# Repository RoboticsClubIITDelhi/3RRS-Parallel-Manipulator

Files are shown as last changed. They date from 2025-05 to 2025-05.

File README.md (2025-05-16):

# Robotics Project 2025

<div align="center">
  
  
  
  <div align="center">
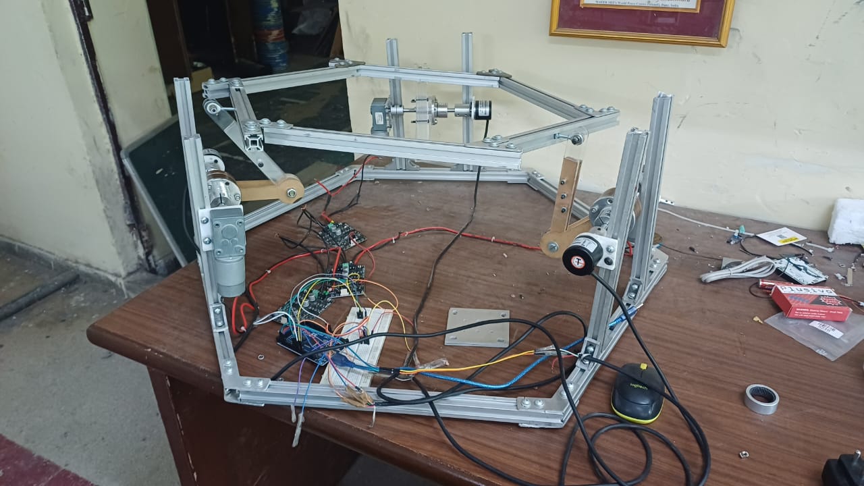
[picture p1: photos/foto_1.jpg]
Project Image
    
    <br> 
  </div>
</div>

## 🤖 Project Overview

This repository houses the codebase for the **3RRS Parallel Manipulator**. It serves as a comprehensive collection of resources, including code, CAD models, calculations, and component datasheets. We aim to create a well-documented reference that will enable future teams to build upon our work.

### 🎯 Key Features

- ✅ Robust Mechanism Design
- ✅ Efficient and Fast Inverse Kinematics
- ✅ Precise Orientation with minimal lag

## 🧠 Algorithm Development
The Inverse Kinematics have been completely solved, coded, and used in multiple applications, one being a ball balancing robot. 

## 📚 Resources
- [Intro to Serial and Parallel Manipulators](https://youtu.be/ZZrNe40jpSA?si=esQ4bNgmhpNv93w0)
- [Inverse Kinematics with the example of a Ball Balancing Bot](https://youtu.be/-1pX518wlu8?si=GbBtG65QNJ148i5c)
- [Research Paper on Kinematics and Dynamics of a 3RRS Parallel Manipulator](https://www.researchgate.net/publication/3902626_Inverse_kinematics_and_dynamics_of_the_3-RRS_parallel_platform)

### Software Utilised
- Autodesk Fusion 360
- Python
- Arduino IDE

### Hardware Utilised
- DC Geared Motors
- Rotary Encoders
- Motor Drivers
- Arduino Mega

## 🤝 Contributor Notes
- We follow the [standard Git workflow](https://www.geeksforgeeks.org/git-workflows-with-open-source-collaboration/) for collaboration
- Suggestions for improvement are welcome via **Issues** or Discussions.

---

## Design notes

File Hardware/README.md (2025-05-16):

# Hardware Documentation

<div align="center">
  
  
  
</div>

## 🔧 Hardware Specifications

- **Dimensions**: 700x800x180mm 
- **Sensors**: Rotary Encoders
- **Power**: 11.1V LiPo battery

## 🔌 Electronics Design

### Base Configuration
- **Microcontroller**: Arduino Mega 2560
- **Motor Driver**: Cytron MDD10A
- **Sensor Interface**: Interrupt based rotary encoders

## 📋 Bill of Materials
1. [DC Motors](https://robu.in/product/et-wgm58-a-high-torque-low-noise-90-degree-right-angle-1-100rpm-12v-dc-worm-gear-motor/) x 3
2. [Rotary Encoders](https://robu.in/product/incremental-optical-rotary-encoder-6002400-pulse-600-ppr/) x 3
3. [Motor Drivers](https://robu.in/product/dual-channel-enhanced-13amp-dc-motor-driver-30a-peak/) x 2
4. [Arduino Mega](https://robu.in/product/original-arduino-mega-2560-atmega2560-mcu-rev3/) x 1
5. Mechanical Hardware (X-channels, Acrylic, Wheel Hubs, Rod ends) 
---

<div align="center">
  <i>For software documentation, please see the <a href="../CodeBase/README.md">Software README</a></i>
</div>

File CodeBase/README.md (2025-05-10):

# Software Documentation

<div align="center">
  
  
  
</div>

## 📁 Software Architecture

The software for the 3RRS Parallel Manipulator project is designed with precision in mind.
It consists of two major divisions:-
1. Control System for controlling the angle of rotation of motors with the help of a PID controller
2. Inverse Kinematics to calculate the angle of rotation of the three motors for the required orientation and height of the end effector

<div align="center">
  <i>For hardware documentation, please see the <a href="../Hardware/README.md">Hardware README</a></i>
</div>

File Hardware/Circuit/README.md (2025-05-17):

This folder contains the circuit diagram.<br><br>
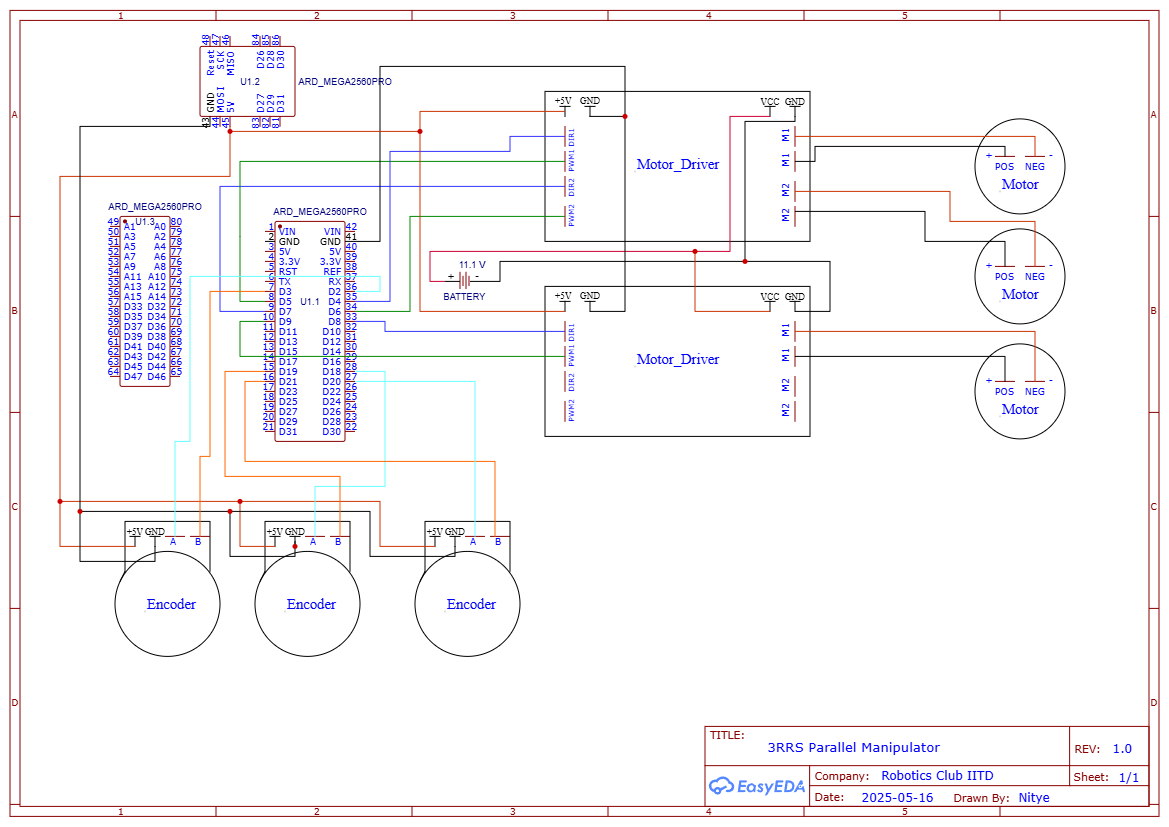
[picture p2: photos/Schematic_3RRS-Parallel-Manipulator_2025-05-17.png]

<h2>Important points</h2>
<ul>
  <li>
   Encoders work based on interrupts, so use a microcontroller with enough interrupt pins; not all pins can handle interrupts.
   In Arduino Uno, there are only 2 interrupt pins which is why we used Arduino Mega, which has 6 pins.
  </li>
  <li>
    Might have to switch the motor driver to a bigger capacity model if using both channels of the driver and using heavy motors.
  </li>
</ul>

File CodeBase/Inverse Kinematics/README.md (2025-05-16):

This folder contains the code for inverse kinematics of the 3RRS Parallel Manipulator.<br>
The Inverse Kinematics is calculated with the help of this research paper.<br>
[Inverse Kinematics and Dynamics of 3RRS Parallel Manipulator](https://www.researchgate.net/publication/3902626_Inverse_kinematics_and_dynamics_of_the_3-RRS_parallel_platform)<br>
This is a simpler video explaining the inverse kinematics.<br>
[Inverse Kinematics of 3RRS Parallel Manipulator](https://www.youtube.com/watch?v=-1pX518wlu8)

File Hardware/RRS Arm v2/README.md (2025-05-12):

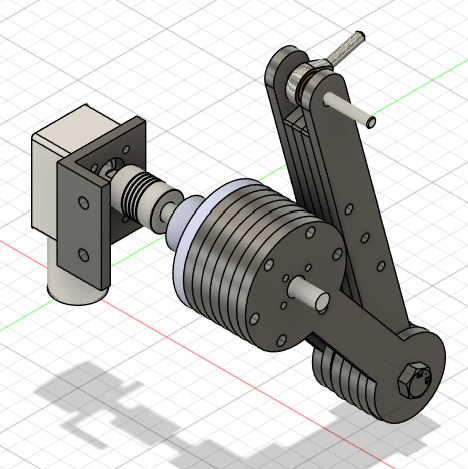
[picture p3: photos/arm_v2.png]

<b>Designer: </b> Nitye Gupta<br>
This directory contains the CAD files for the first iteration of an RRS arm.<br>
The Spherical joint has been switched to a true spherical joint.<br>
The Spherical joint has been made using a 5 mm male rod end.<br>
The Revolute joints have been made using 8 mm bore ball bearings.<br>
The arm links have been fabricated using 5 mm thick acrylic.

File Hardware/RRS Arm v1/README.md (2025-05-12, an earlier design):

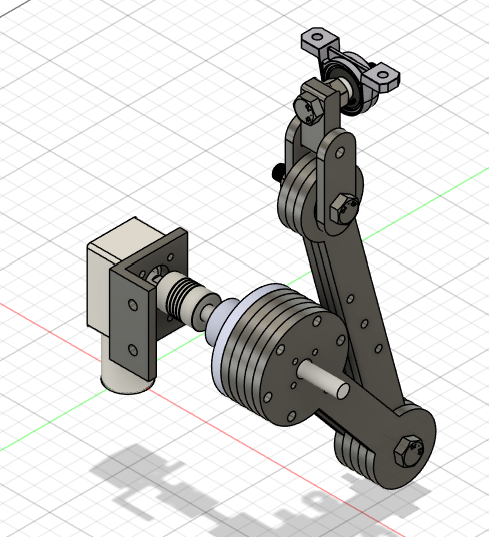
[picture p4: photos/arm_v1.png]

<b>Designer:</b> Nitye Gupta<br>
This directory contains the CAD files for the first iteration of an RRS arm.<br>
In reality, the Spherical joint is not a true spherical joint, but rather a combination of two Revolute joints whose axes intersect orthogonally.<br>
The Revolute joints have been made using 8 mm bore ball bearings.<br>
The arm links have been fabricated using 5 mm thick acrylic.

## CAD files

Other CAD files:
Hardware/RRS Arm v1/100 mm link v15.ipt
Hardware/RRS Arm v1/12V DC Motor.ipt
Hardware/RRS Arm v1/160 mm link v14.ipt
Hardware/RRS Arm v1/608RS v2.iam
Hardware/RRS Arm v1/608RS v2_1.iam
Hardware/RRS Arm v1/608RS.ipt
Hardware/RRS Arm v1/608RS_1.ipt
Hardware/RRS Arm v1/8mm shaft collar v2 v3.ipt
Hardware/RRS Arm v1/8x100 mm shaft v3.ipt
Hardware/RRS Arm v1/90 degree Geared DC Motor v2.iam
Hardware/RRS Arm v1/Arm Assembly.iam
Hardware/RRS Arm v1/Flexible Coupling v1.ipt
Hardware/RRS Arm v1/Gearbox.ipt
Hardware/RRS Arm v1/Hex bolt M8x40 v1.ipt
Hardware/RRS Arm v1/KP08 v3.iam
Hardware/RRS Arm v1/KP08.ipt
Hardware/RRS Arm v1/M8 Nut v5 v1.ipt
Hardware/RRS Arm v1/Motor Mount v4.ipt
Hardware/RRS Arm v1/Output Shaft.ipt
Hardware/RRS Arm v1/Universal Joint Link v22.ipt
Hardware/RRS Arm v1/Wheel Hub 8 mm v1.ipt
Hardware/RRS Arm v1/Wheel Hub Plate v5.ipt
Hardware/RRS Arm v2/100 mm link v15.ipt
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

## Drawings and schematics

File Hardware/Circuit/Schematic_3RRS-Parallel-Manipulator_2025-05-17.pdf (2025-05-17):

## Motor

## Motor_Driver

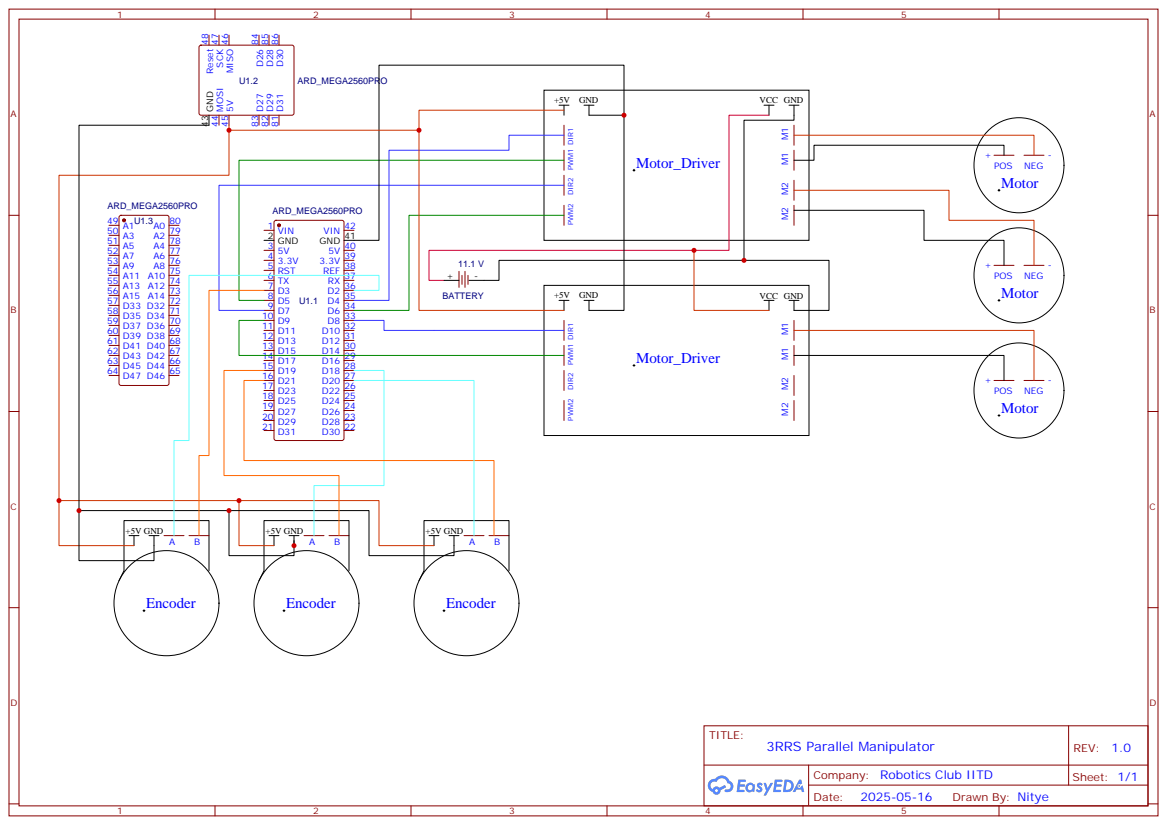
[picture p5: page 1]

VCC GND M¹ M¹ M² M² M² M² M¹ M¹

Company: Robotics Club IITD

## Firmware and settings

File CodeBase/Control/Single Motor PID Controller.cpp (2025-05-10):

// Cytron Motor Driver Position Control with PID - Serial Input for Target Position
// Input is in pulse counts of encoder, not angle of motor

// Define motor driver pins
#define PWM_PIN 9       // PWM control pin (connect to PWM input on the driver)
#define DIR_PIN 8       // Direction control pin (connect to DIR input on the driver)
#define ENCODER_A 2     // Encoder signal A (Connect to an interrupt pin)
#define ENCODER_B 3     // Encoder signal B (Connect to an interrupt pin)

volatile long encoderCount = 0; // Encoder pulse count (changed to long for larger range)
unsigned long prevTime = 0;
float prevError = 0, integral = 0;

// PID Constants
float Kp = 2;
float Ki = 4.2;
float Kd = 0.09;

// Desired position in encoder counts
long targetPosition = 0;

void setup() {
    pinMode(PWM_PIN, OUTPUT);
    pinMode(DIR_PIN, OUTPUT);
    pinMode(ENCODER_A, INPUT_PULLUP);
    pinMode(ENCODER_B, INPUT_PULLUP);
    attachInterrupt(digitalPinToInterrupt(ENCODER_A), countEncoder, RISING);
    Serial.begin(9600);
    Serial.println("Enter target position:");
}

void countEncoder() {
    if (digitalRead(ENCODER_B) == HIGH) {
        encoderCount++;
    } else {
        encoderCount--;
    }
}

void setMotor(int speed) {
    digitalWrite(DIR_PIN, speed >= 0 ? HIGH : LOW);
    analogWrite(PWM_PIN, constrain(abs(speed), 0, 255));
}

void loop() {
    // Read target position from Serial
    if (Serial.available() > 0) {
        targetPosition = Serial.parseInt();
        Serial.print("New Target Position: ");
        Serial.println(targetPosition);
        // Clear the input buffer
        while(Serial.available() > 0) {
            Serial.read();
        }
    }
    
    unsigned long currentTime = millis();
    float dt = (currentTime - prevTime) / 1000.0; // Convert to seconds
    if (dt >= 0.05) { // Run control loop every 100ms
        float error = targetPosition - encoderCount;
        integral += error * dt;
        float derivative = (error - prevError) / dt;
        float output = (Kp * error) + (Ki * integral) + (Kd * derivative);
        if (error>0){
          output = (0.6*Kp * error) + (3 * integral) + (Kd * derivative);}
        
        setMotor(output);
        
        prevError = error;
        prevTime = currentTime;


        Serial.print("Target: "); Serial.print(targetPosition);
        Serial.print(" | Current: "); Serial.print(encoderCount);
        Serial.print(" | PWM: "); Serial.println(output);
    }
}

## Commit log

2025-05-10 Create Single Motor PID Controller
2025-05-10 Create Three Motor PID Controller
2025-05-12 CAD files for version 1 uploaded
    [100 mm link v15.ipt, 12V DC Motor.ipt, 160 mm link v14.ipt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]
2025-05-12 Arm photos uploaded
2025-05-12 Added CAD files for RRS Arm v2
    [100 mm link v15.ipt, 12V DC Motor.ipt, 160 mm Spherical link Filler v3.ipt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]
2025-05-17 Added Circuit Diagram
2025-05-17 Added circuit photo
2025-08-12 Added Inverse Kinematics files
